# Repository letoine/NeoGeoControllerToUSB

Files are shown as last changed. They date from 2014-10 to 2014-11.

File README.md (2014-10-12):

NeoGeoControllerToUSB
=====================

Simple adapter that transforms a NeoGeo controller into a USB controller.

NeoGeo controller pinout
========================

NeoGeo controller connector is a DB15. NeoGeo controller only has four (4)
buttons (A, B, C, D). The D button is connected to pins 9 and 4, but the
console only cheks for pin 4. Pins 10 and 2 are not connected.

Some superguns uses a DB15 for the controller with a compatible pinout. These
superguns are using the non-connected pins to support games with more than
four buttons, like capcom games using the kick-harness.

DB15 pinout controller
-------------------------
\ 1 2  3  4  5  6  7  8 /
 \ 9 10 11 12 13 14 15 /
  --------------------

pin |    function    | comment
----|----------------|--------------
 1  | +5V            |
 2  | Down           |
 3  | Right          |
 4  | B button       | 
 5  | D button       |
 6  | Select         |
 7  | NC/Kick1       | Not connected on NeoGeo, used for kick in superguns.
 8  | GND            | 
 9  | Up             | 
10  | Left           | 
11  | A button       | 
12  | C button       | 
13  | Start          | 
14  | NC/Kick3       | Not connected on NeoGeo, used for kick in superguns.
15  | D button/Kick2 | Not read by console, used for kick in superguns.

ATMega pins/Controller mapping
=========================

 IO | DB-Pin |  button
----|--------|--------
PB0 |    4   |  B
PB1 |   12   |  C
PB2 |    5   |  D
PB3 |    6   |  Select
PB4 |   13   |  Start
PB5 |    7   |  Kick_1
PB6 |   14   |  Kick_3
PB7 |   15   |  D/Kick_2
PC2 |   11   |  A
PD0 |   10   |  Left
PD1 |    9   |  Up
PD2 |    -   |   -
PD3 |    -   |   -
PD4 |    2   |  Down
PD5 |    3   |  Right
PD6 |    -   |   -
PD7 |    -   |   -

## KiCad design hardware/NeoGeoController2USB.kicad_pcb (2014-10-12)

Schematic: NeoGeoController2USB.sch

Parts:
C1, C2: 22p
C3, C5: 100nf
C4: 1uf
CON1: AVR-ISP6; AVR-ISP-6
CON2: TTL_6
J1: USB
J2: DB15
R1, R2, R4, R5, R6: 22ohms
R3: 10K
U1: ATMEGA32U2-AU
X1: 16Mhz

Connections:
A_BUTTON: J2.11 (P111), U1.21
B_BUTTON: J2.4, R5.2
C_BUTTON: J2.12, R4.2
DOWN: J2.2, U1.18
D_BUTTON: J2.5, U1.14
D_KICK_2: J2.15, U1.7
GND: C1.2, C2.2, C3.1, C4.1, C5.2, CON1.6 (GND), CON2.1 (GND), J1.4 (GND), J1.5 (Shield_1), J1.6 (Shield_2), J2.8, U1.3, U1.28
KICK_1: J2.7, U1.10
KICK_3: J2.14, U1.6
LEFT: J2.10, U1.20
MISO: CON1.1 (MISO), R6.1, U1.17
MOSI: CON1.4 (MOSI), R5.1, U1.16
unnamed: J1.3 (D+), R2.1
unnamed: J1.2 (D-), R1.1
unnamed: R1.2, U1.30
unnamed: C4.2, U1.27
unnamed: CON2.4 (TX), U1.9
unnamed: CON2.2 (~CTS~), U1.13
unnamed: CON2.6 (~RTS~), U1.12
unnamed: CON2.5 (RX), U1.8
unnamed: R2.2, U1.29
unnamed: C1.1, U1.1, X1.1
unnamed: C2.1, U1.2, X1.2
RESET: C5.1, CON1.5 (RST), R3.2, U1.24
RIGHT: J2.3, R6.2
SCK: CON1.3 (SCK), R4.1, U1.15
SELECT: J2.6, U1.11
START: J2.13, U1.5
UP: J2.9, U1.19
VCC: C3.2, CON1.2 (VCC), CON2.3 (VCC), J1.1 (Vbus), J2.1, R3.1, U1.4, U1.31, U1.32

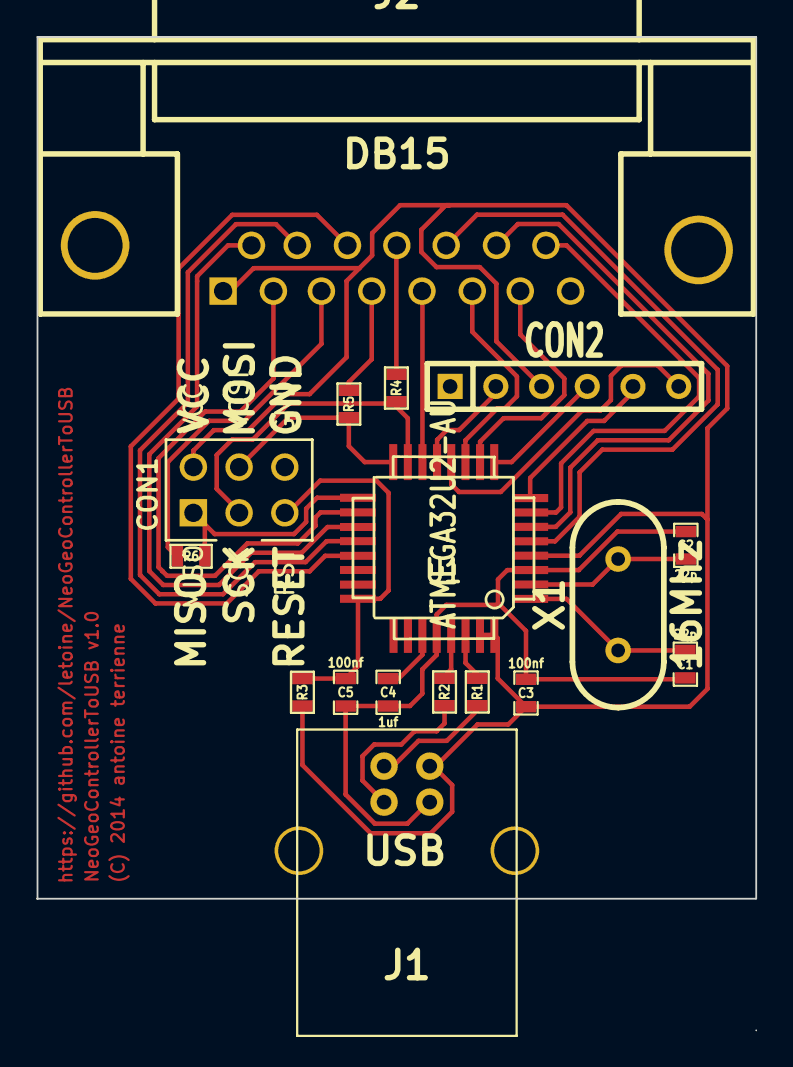
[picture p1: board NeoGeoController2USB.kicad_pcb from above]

Board: 2 copper layers, 40.0 x 47.9 mm, 17 parts (0 on the bottom side), 30 nets.

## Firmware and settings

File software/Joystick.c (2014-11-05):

#include "Joystick.h"

static uint8_t PrevJoystickHIDReportBuffer[sizeof(USB_JoystickReport_Data_t)];

USB_ClassInfo_HID_Device_t Joystick_HID_Interface = {
  .Config = {
    .InterfaceNumber = INTERFACE_ID_Joystick,
    .ReportINEndpoint = {
      .Address              = JOYSTICK_EPADDR,
      .Size                 = JOYSTICK_EPSIZE,
      .Banks                = 1,
    },
    .PrevReportINBuffer           = PrevJoystickHIDReportBuffer,
    .PrevReportINBufferSize       = sizeof(PrevJoystickHIDReportBuffer),
  },
};

static union {
  uint8_t raw[1];
  struct {
    unsigned int is_neo_geo_stick:1;
  };
} status;

typedef union {
  uint8_t raw;
  struct {
    unsigned int b_button:1;
    unsigned int c_button:1;
    unsigned int d_button:1;
    unsigned int select:1;
    
    unsigned int start:1;
    unsigned int kick1:1;
    unsigned int kick3:1;
    unsigned int d_kick2:1;
  };
} portb_defs;

typedef union {
  uint8_t raw;
  struct {
    unsigned int pad1:2;
    unsigned int a_button:1;
    unsigned int pad2:5;
  };
} portc_defs;

typedef union {
  uint8_t raw;
  struct {
    unsigned int left:1;
    unsigned int up:1;
    unsigned int pad1:2;
    
    unsigned int down:1;
    unsigned int right:1;
    unsigned int pad2:2;
  };
} portd_defs;

int main(void) {
  SetupHardware();
  
  GlobalInterruptEnable();
  
  for (;;) {
    HID_Device_USBTask(&Joystick_HID_Interface);
    USB_USBTask();
  }
}



void SetupHardware(void) {
  /* Disable watchdog if enabled by bootloader/fuses */
  MCUSR &= ~(1 << WDRF);
  wdt_disable();
  
  /* Disable clock division */
  clock_prescale_set(clock_div_1);
  
  status.is_neo_geo_stick = 1;
  
  /* Hardware Initialization */
  /* Port B all pins are input with pull=up resistor enabled */
  DDRB = 0;
  PORTB = 0xFF;
  /* Port C we only use pin 2 */
  DDRC &= ~(1<<DDC2);
  PORTC |= (1<<PORTC2);
  /* Port D we use ping 0-1, 4-5 */
  DDRD = 0xFF;
  PORTD = 0x33;
  
  SerialDebug_init();
  USB_Init();
}

void EVENT_USB_Device_ConfigurationChanged(void) {
  bool ConfigSuccess = true;
  
  SerialDebug_printf("EVENT_USB_Device_ConfigurationChanged\r\n");
  ConfigSuccess &= HID_Device_ConfigureEndpoints(&Joystick_HID_Interface);
  
  USB_Device_EnableSOFEvents();
}

void EVENT_USB_Device_ControlRequest(void) {
  SerialDebug_printf("EVENT_USB_Device_ControlRequest\r\n");
  HID_Device_ProcessControlRequest(&Joystick_HID_Interface);
}

void EVENT_USB_Device_StartOfFrame(void) {
  //SerialDebug_printf("EVENT_USB_Device_StartOfFrame\r\n");
  HID_Device_MillisecondElapsed(&Joystick_HID_Interface);
}

bool CALLBACK_HID_Device_CreateHIDReport(USB_ClassInfo_HID_Device_t* const HIDInterfaceInfo,
                                         uint8_t* const ReportID,
                                         const uint8_t ReportType,
                                         void* ReportData,
                                         uint16_t* const ReportSize)
{
  USB_JoystickReport_Data_t* JoystickReport = (USB_JoystickReport_Data_t*)ReportData;
  
  portd_defs dport;
  portc_defs cport;
  portb_defs bport;
  
  dport.raw = PIND;
  cport.raw = PINC;
  bport.raw = PINB;
  
  JoystickReport->Y = 0;
  JoystickReport->X = 0;
  JoystickReport->button.raw[0] = 0;
  JoystickReport->button.raw[1] = 0;
  
  if (!dport.up)
    JoystickReport->Y = -127;
  else if (!dport.down)
    JoystickReport->Y =  127;
  
  if (!dport.left)
    JoystickReport->X = -127;
  else if (!dport.right)
    JoystickReport->X =  127;
  
  if (!cport.a_button)
    JoystickReport->button.square = 1;
  
  if (!bport.b_button)
    JoystickReport->button.cross = 1;
  
  if (!bport.c_button)
    JoystickReport->button.circle = 1;
  
  if (!bport.d_button)
    JoystickReport->button.triangle = 1;
  
  if (!bport.start && bport.select)
    JoystickReport->button.start = 1;
  
  if (!bport.select && bport.start)
    JoystickReport->button.select = 1;
  
  if (!bport.start && !bport.select)
    JoystickReport->button.home = 1;
  
  if (!bport.kick1) {
    JoystickReport->button.l1 = 1;
  }
  
  if (!!bport.kick3) {
    JoystickReport->button.r1 = 1;
  }
  
  if (bport.d_button != bport.d_kick2) {
    status.is_neo_geo_stick = 0;
  }
  
  if (status.is_neo_geo_stick == 0 && !bport.d_kick2) {
    JoystickReport->button.r2 = 1;
  }
  
  *ReportSize = sizeof(USB_JoystickReport_Data_t);
  return false;
}

void CALLBACK_HID_Device_ProcessHIDReport(USB_ClassInfo_HID_Device_t* const HIDInterfaceInfo,
                                          const uint8_t ReportID,
                                          const uint8_t ReportType,
                                          const void* ReportData,
                                          const uint16_t ReportSize)
{
  SerialDebug_printf("CALLBACK_HID_Device_ProcessHIDReport\r\n");
  SerialDebug_printf("%#0x, %#0x\r\n", ReportID, ReportType);
  SerialDebug_printByteArray(ReportData, ReportSize);
  
  // Unused (but mandatory for the HID class driver) in this demo, since there are no Host->Device reports
}

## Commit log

2014-08-02 Update shematics. Work in progress.
    [NeoGeoController2USB.sch]
2014-08-03 Board development in progress.
    [NeoGeoController2USB.kicad_pcb, NeoGeoController2USB.sch]
2014-08-03 First version fo the pcb.
    [NeoGeoController2USB.kicad_pcb, NeoGeoController2USB.sch]
2014-08-05 Shrinking board.
    [NeoGeoController2USB.kicad_pcb, NeoGeoController2USB.sch]
2014-09-07 Adding software.
    [NeoGeoController2USB.kicad_pcb, NeoGeoController2USB.sch]
2014-10-12 Adding access to serial port. Fix controller pinout numering.
    [NeoGeoController2USB.kicad_pcb, NeoGeoController2USB.sch]
2014-11-05 Adding serial debug to trace operation.
2014-12-09 Removing kicad temp files.

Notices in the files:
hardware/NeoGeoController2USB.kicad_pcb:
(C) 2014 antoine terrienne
